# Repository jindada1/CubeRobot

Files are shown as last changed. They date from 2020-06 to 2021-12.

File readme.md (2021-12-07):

# 三阶魔方还原机器人

基于 python 和 Arduino，实现能够还原三阶魔方的机械结构

## 系统流程

1. 通过摄像头识别魔方颜色
2. 将识别结果转化成魔方求解算法的输入
3. 执行魔方求解算法，得出还原操作序列
3. 指令优化与碰撞规避处理
4. 通过wifi将序列发给硬件控制器
5. 硬件控制器按照序列，控制机械结构执行还原
6. over

## 依赖

python 版本: 3.x

+ pywifi
+ pillow
+ numpy
+ opencv-python 

```bash
$ pip install -r requirements.txt
$ python3 guiconfig.py
```

## 开发

### 软件部分

- [x] tkinter gui [组件](https://github.com/jindada1/CubeRobot/tree/master/components)的设计与开发

  - [x] Camera：基于cv2.VideoCapture 构造的摄像头管理类 
  
  - [x] HoverButton：基于 tk.Button 提供可带参数事件绑定接口，并做了些许美化
  
  - [x] ViewCanvas：**颜色数据采集与调试工具**中的面板，用于展示视频与图片
  
  - [x] CubeFloorPlan：用于绘制并管理魔方平面展开图，存储并管理整个魔方的色块分布，并生成魔方色块序列
  
  - [x] HSVAdjuster：**颜色数据采集与调试工具**中的面板，实时调整颜色识别中使用的 hsv 范围并保存
  
  - [x] SampleAdjuster：**颜色数据采集与调试工具**中的面板，实时调整用于颜色识别的采样范围并保存

  - [x] Console：控制台模块，用于**主控程序**运行时的状态输出

  - [x] Window：Tk 窗口的封装，提供了 update_func 接口
  
  - [x] CameraCanvas：摄像头视频展示面板，用于**主控程序**

- [x] [颜色数据采集与调试工具](https://github.com/jindada1/CubeRobot/blob/master/guiconfig.py)的开发

  - [x] [数据设置与加载模块](https://github.com/jindada1/CubeRobot/tree/master/setting)

  - [x] [计算机视觉模块](https://github.com/jindada1/CubeRobot/blob/master/vision.py)：魔方定位与颜色块的识别

    - [x] 全局二值化色块定位
  
    - [x] 形态学处理与魔方定位
  
    - [x] 手动定位，固定点采样
  
    - [x] 颜色识别

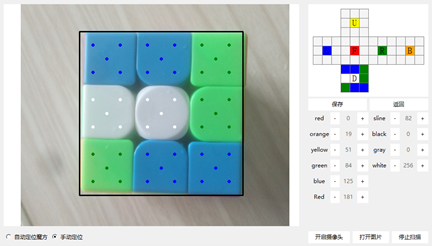
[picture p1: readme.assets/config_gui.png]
config_gui
  
  
- [x] [魔方模拟器](https://github.com/jindada1/CubeRobot/blob/master/sock/emulator.html)的开发

  - [x] 虚拟魔方的实现
- [x] 执行还原序列
  - [x] 获取魔方状态
- [x] twophase 求解接口的[后台服务器](https://github.com/jindada1/CubeRobot/blob/master/sock/http_server.py)
  
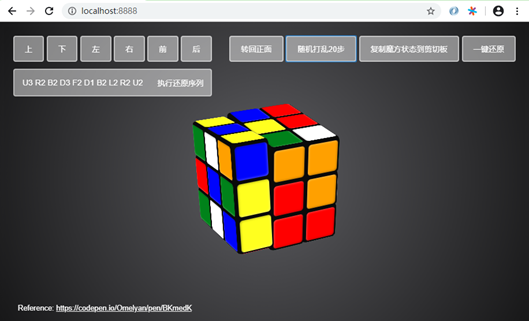
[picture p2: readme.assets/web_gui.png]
web_gui


- [x] 主控程序的开发

  - [x] [计算机视觉模块](https://github.com/jindada1/CubeRobot/blob/master/vision.py)：魔方定位与颜色块的识别
  - [x] [魔方求解模块](https://github.com/jindada1/CubeRobot/tree/master/twophase)：[twophase](https://github.com/hkociemba/RubiksCube-TwophaseSolver)算法
  - [x] 指令调整与优化
    
    - [x] 机器动作指令集的设计
    
    - [x] 标准还原序列到机器动作指令序列的转化
    
    - [x] 碰撞规避处理
  - [x] [wifi模块](https://github.com/jindada1/CubeRobot/blob/master/sock/esp_client.py)
  
    - [x] wifi检测与连接
    - [x] 自动获取 esp8266 模块在 ap 模式下的 ip 地址
    - [x] 发送数据和接收数据
  
  软件架构如下：
  
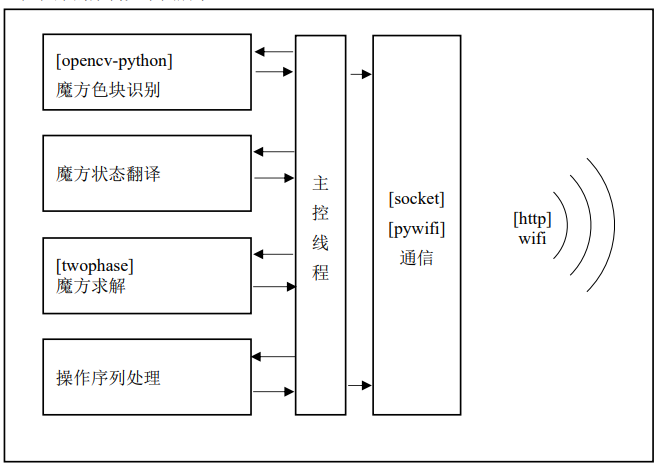
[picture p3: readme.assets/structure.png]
structure
  
  
  界面如下：
  
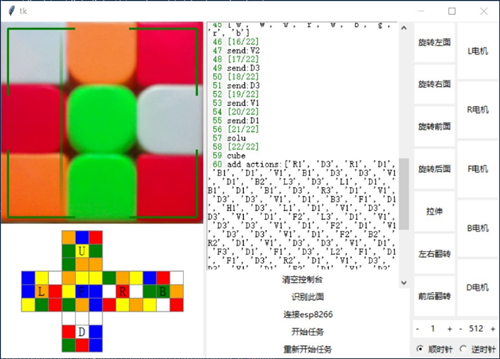
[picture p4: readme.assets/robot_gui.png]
robot_gui
  

### 硬件部分

- [x] esp8266

  - [x] ap 模式

  - [x] 提供路由处理来自客户端的请求，并返回处理结果

- [x] 操作序列的解析

- [x] 电机控制逻辑

  - [x] 单个电机动作控制

  - [x] 多个电机同步运行

  - [x] 单个电机角度微调

单个电机的基本连接如下：

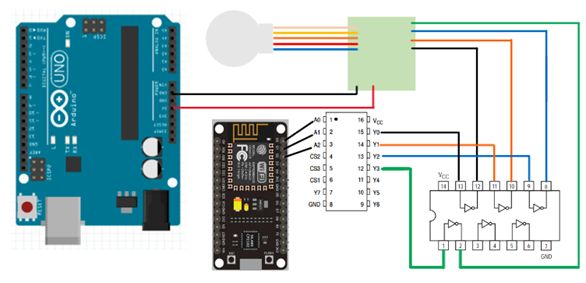
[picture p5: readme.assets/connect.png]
connect


## 机械结构建模

模型及装配体如下图所示，所有原文件在[sldprt](/models/sldprt)目录下

凹槽凸轮

导出的3D打印模型在[stl](/models/stl)目录下

### 动图演示

凹槽凸轮             |  魔方翻转       
:-------------------------:|:-------------------------:
  |  

|装配爆炸视图           |
|:-------------------------:|
|  |

### 实物照片

翻转魔方             |  魔鬼接线       
:-------------------------:|:-------------------------:
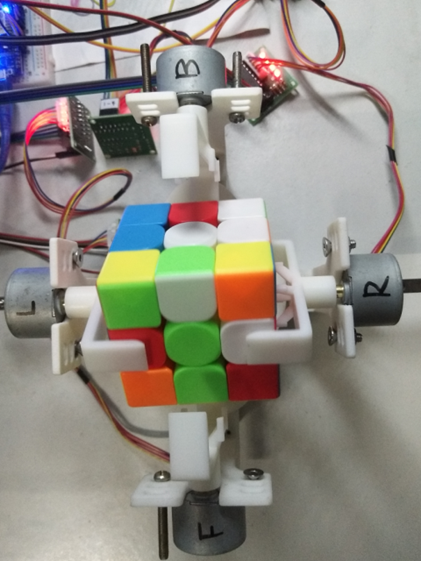
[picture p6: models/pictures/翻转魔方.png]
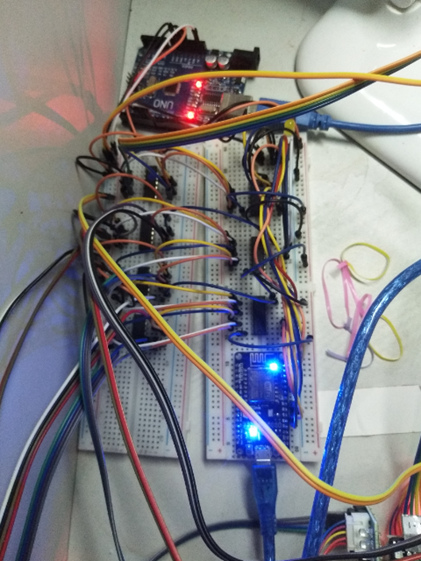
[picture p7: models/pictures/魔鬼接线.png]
  |  

识别魔方色块分布             |  旋转魔方面       
:-------------------------:|:-------------------------:
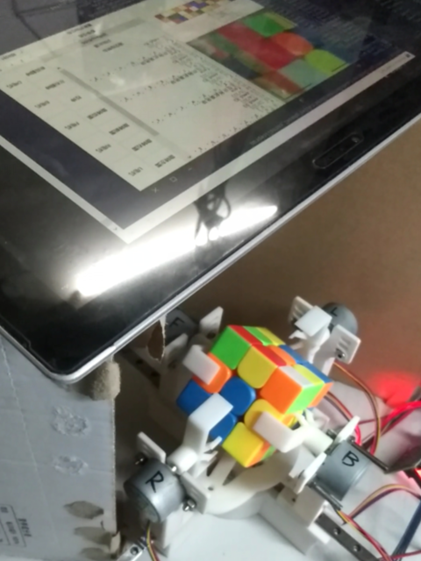
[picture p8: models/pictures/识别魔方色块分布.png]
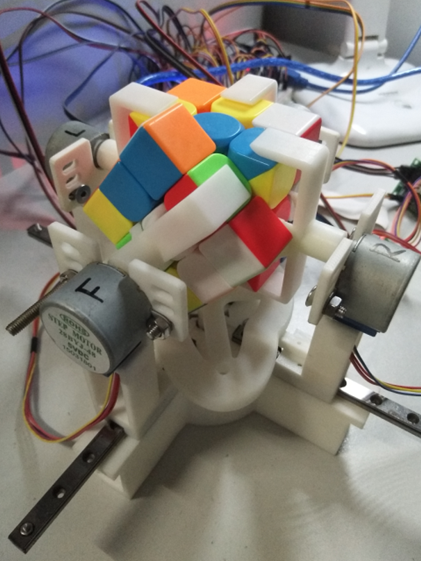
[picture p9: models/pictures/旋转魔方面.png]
  |

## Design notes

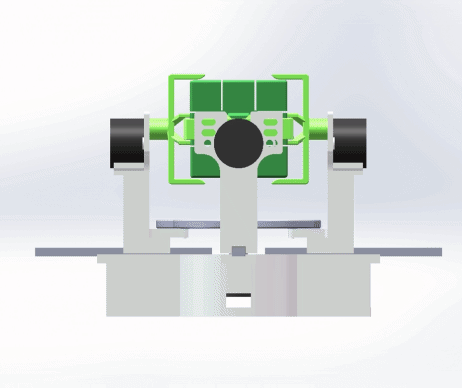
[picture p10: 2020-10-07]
models/screenshots/翻转.gif

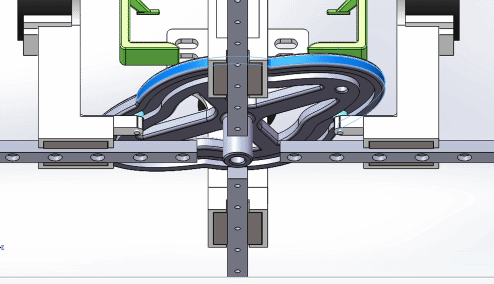
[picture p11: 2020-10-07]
models/screenshots/凹槽凸轮.gif

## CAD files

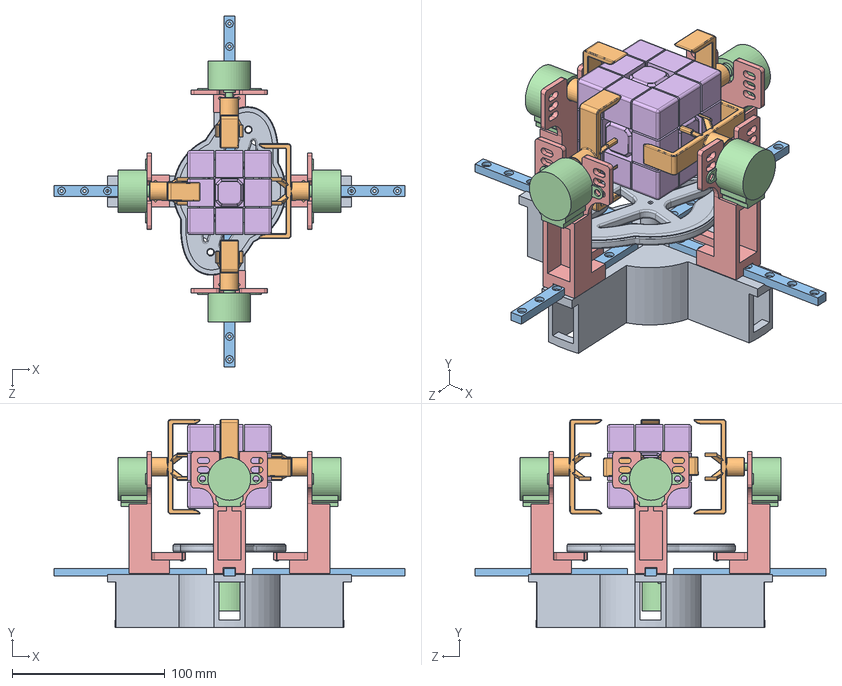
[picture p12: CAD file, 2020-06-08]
models/sldprt/机器人.SLDASM
230.0 x 136.6 x 230.0 mm
外壳
滑块 x 4
导轨 x 4
电机模型 x 5
机械臂拖 x 4
魔方55
轴承 x 5
螺栓m2 x 5
凹槽凸轮---
新抓手 x 4

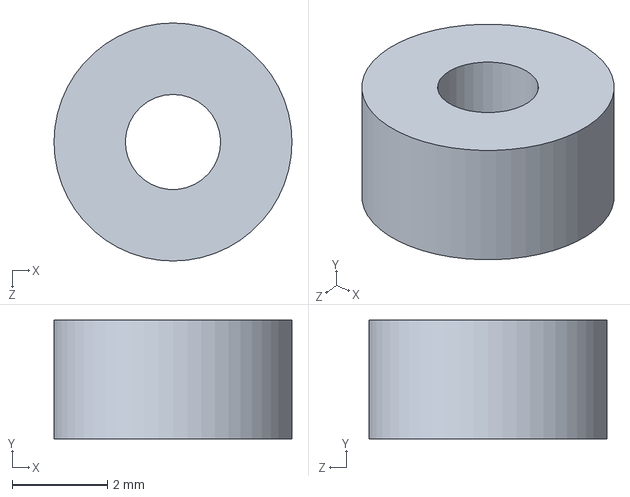
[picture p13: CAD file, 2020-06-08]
models/sldprt/轴承.sldprt
5.00 x 2.50 x 5.00 mm

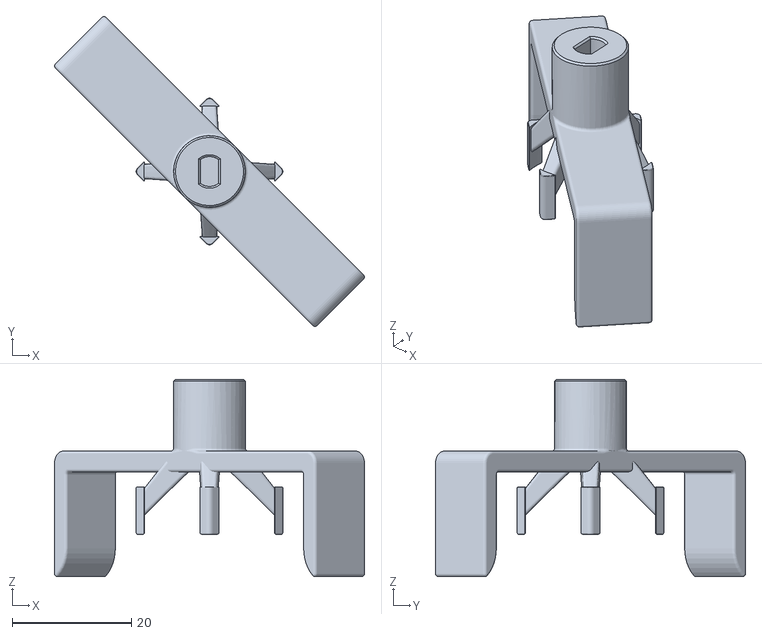
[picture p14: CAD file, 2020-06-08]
models/stl/新爪子x4-sla.STL
51.9 x 51.9 x 33.0

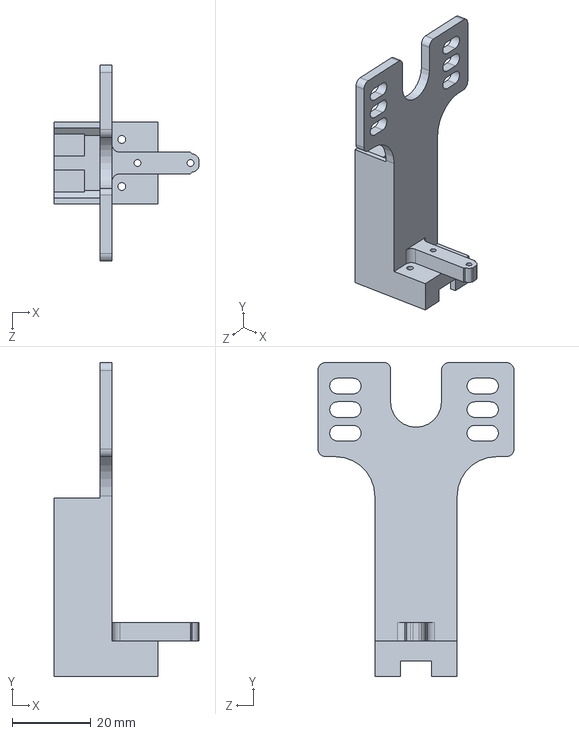
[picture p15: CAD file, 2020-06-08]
models/sldprt/机械臂.SLDPRT
36.9 x 80.0 x 50.0 mm

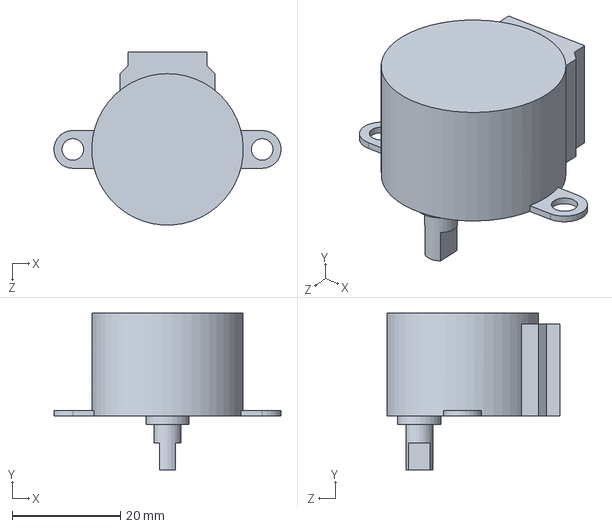
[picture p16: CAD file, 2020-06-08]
models/sldprt/电机模型.sldprt
41.9 x 29.0 x 32.0 mm

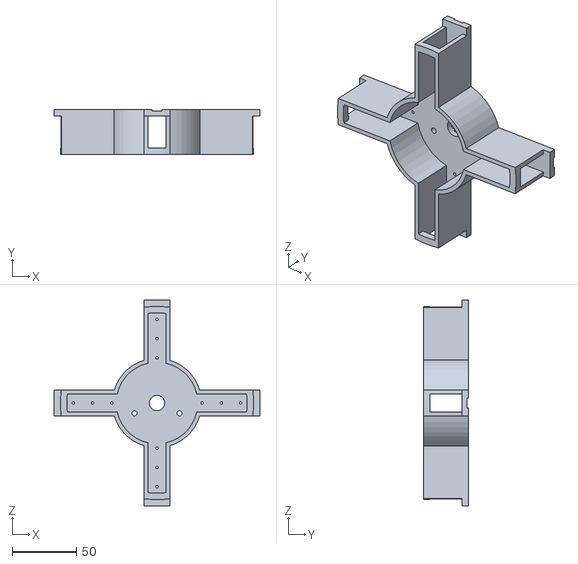
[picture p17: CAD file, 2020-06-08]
models/stl/外壳x1-pla.STL
160.0 x 35.0 x 160.0

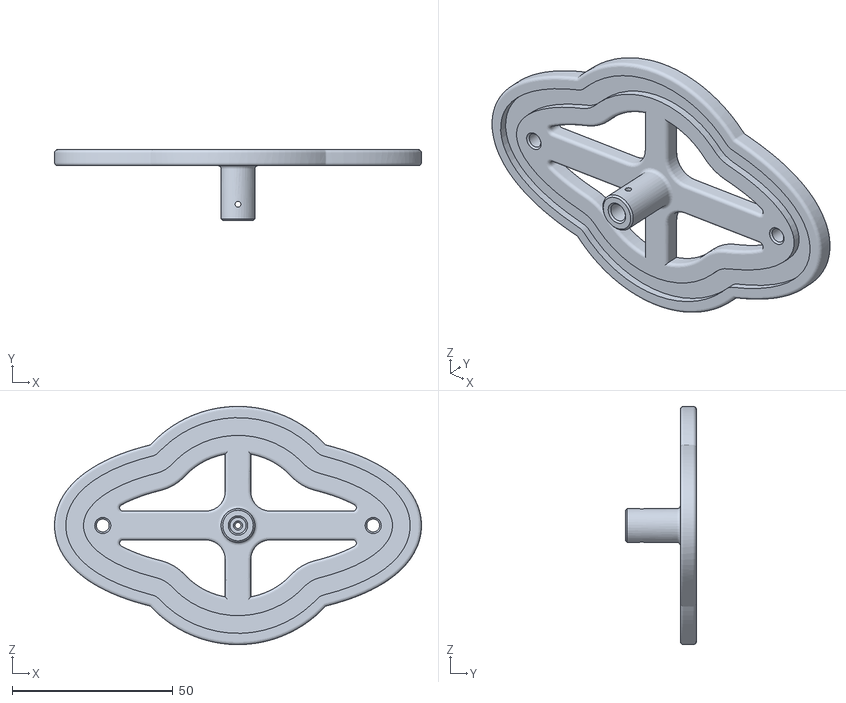
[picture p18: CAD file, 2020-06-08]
models/stl/凹槽凸轮x1-sla .STL
114.0 x 22.0 x 74.0

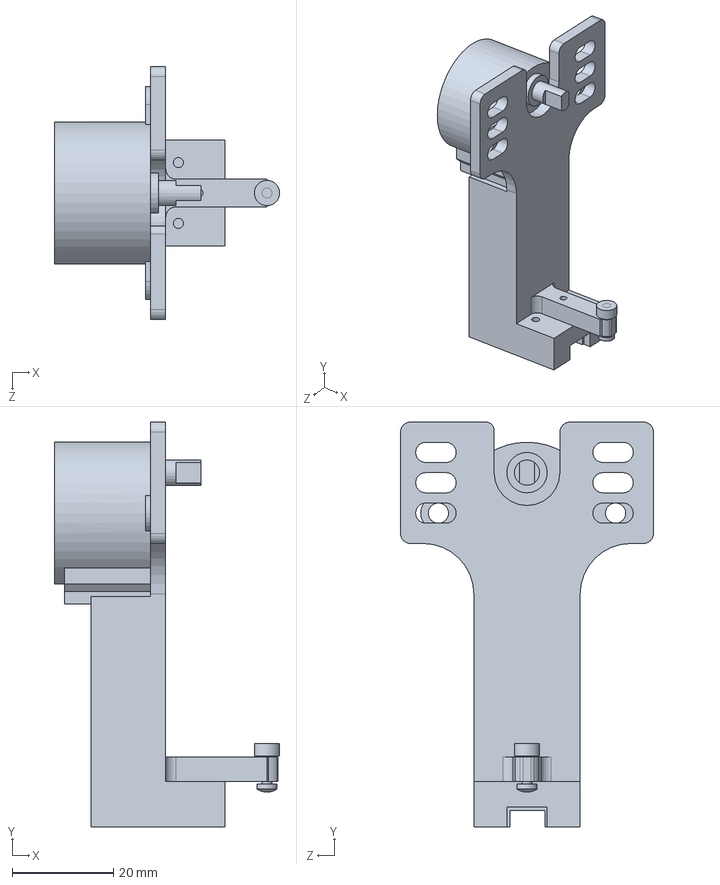
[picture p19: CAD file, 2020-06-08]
models/sldprt/B电机推块装配.SLDPRT
44.5 x 80.0 x 50.0 mm

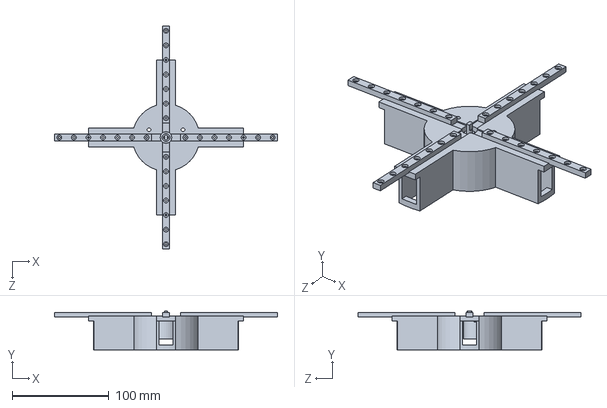
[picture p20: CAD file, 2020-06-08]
models/sldprt/A底座装配.SLDPRT
230.0 x 40.0 x 230.0 mm

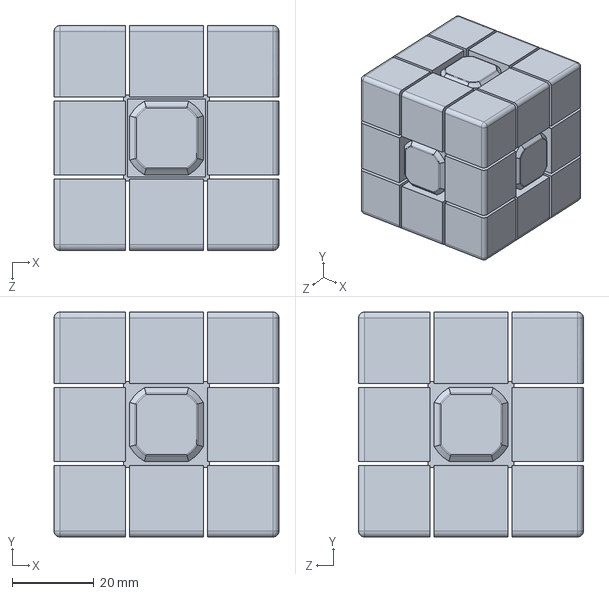
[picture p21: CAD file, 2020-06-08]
models/sldprt/魔方55.sldprt
55.0 x 55.0 x 55.0 mm

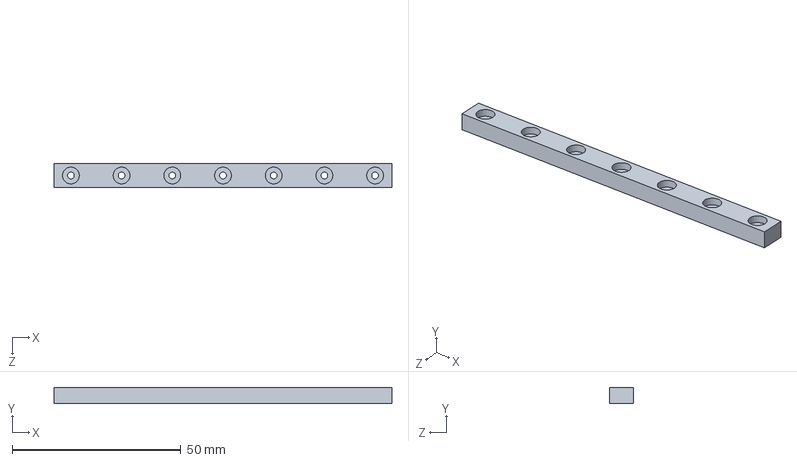
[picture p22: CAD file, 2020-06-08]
models/sldprt/滑轨.SLDPRT
100.0 x 4.80 x 7.00 mm

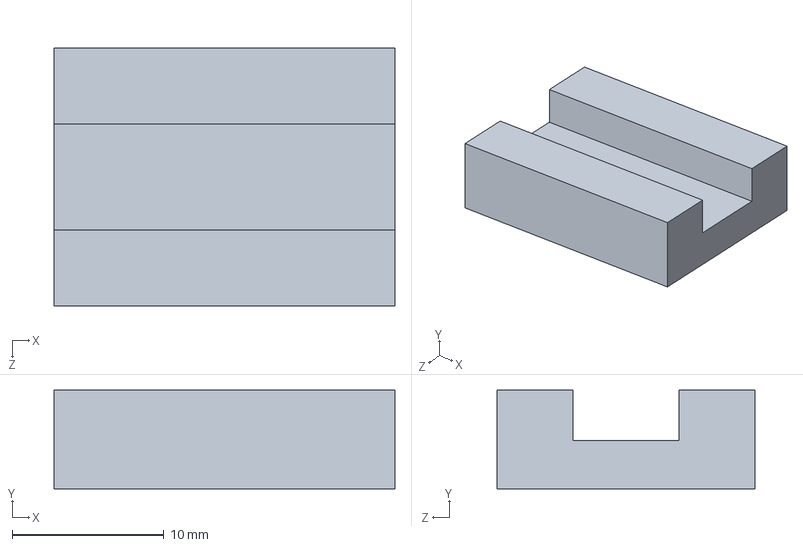
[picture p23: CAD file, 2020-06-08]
models/sldprt/滑块.sldprt
22.5 x 6.50 x 17.0 mm

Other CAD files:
models/stl/机械臂拖x4-pla.STL
models/sldprt/新抓手.SLDPRT
models/sldprt/凹槽凸轮.SLDPRT
models/sldprt/外壳底座.SLDPRT

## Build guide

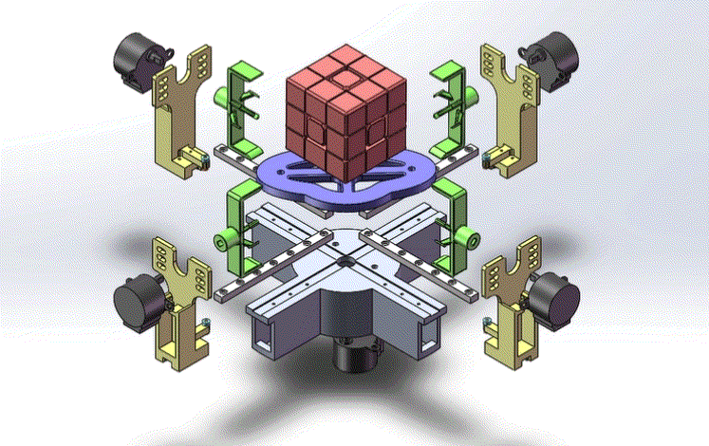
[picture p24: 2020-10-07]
models/screenshots/装配.gif

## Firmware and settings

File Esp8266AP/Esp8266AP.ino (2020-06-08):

/*
   reference:
   1.Getting query parameters
   ->:https://techtutorialsx.com/2016/10/22/esp8266-webserver-getting-query-parameters/
**/

/* Create a WiFi access point and provide a web server on it. */

#include <ESP8266WiFi.h>
#include <WiFiClient.h>
#include <ESP8266WebServer.h>

#ifndef APSSID
#define APSSID "Rubik-Cube"
#define APPSK "1213141516"
#endif

class myStepper
{
public:
  myStepper(int *p, char *cs[4], int r = 512)
  {
    pins = p;
    codes = cs;
    phase = 0;
    pinNum = 3;
    rot = r;
  };

  void step(int dir)
  {
    for (int i = 0; i < pinNum; i++)
    {
      digitalWrite(pins[i], codes[phase][i] == '1');
    }

    phase += dir;
    // dir == 1
    if (phase > 3)
      phase = 0;
    // dir == -1
    else if (phase < 0)
      phase = 3;
  };

  void rotate(int deg, int direct)
  {
    // phase = 0;
    deg = rot * deg;
    while (deg > 0)
    {
      step(direct);
      deg--;
      delay(3);
    }
  };

  void r_steps(int steps, int direct)
  {
    while (steps > 0)
    {
      step(direct);
      steps--;
      delay(3);
    }
  };

  int rots() { return rot; }

private:
  int pinNum;
  int *pins;
  char **codes;
  // 当前高电平所在的相位
  int phase;
  // 单位角度对应的 step 数，也就是90°对应的step数512
  int rot;
};

/* D0 16, D1 5, D2 4, D3 0, D4 2, D5 14, D6 12, D7 13, D8 15 */
int PINS[9] = {0, 2, 4, 5, 12, 13, 14, 15, 16};
char *P1[4] = {"000", "001", "010", "011"};
char *P2[4] = {"100", "101", "110", "111"};

int GROUP_1[3] = {12, 13, 15};
int GROUP_2[3] = {0, 2, 14};
int GROUP_3[3] = {16, 5, 4};

myStepper Left(GROUP_1, P1);
myStepper Right(GROUP_2, P1);
myStepper Front(GROUP_1, P2);
myStepper Back(GROUP_2, P2);
myStepper Down(GROUP_3, P1, 256);

/* Set these to your desired credentials. */
const char *ssid = APSSID;
const char *password = APPSK;

ESP8266WebServer server(80);

void initPins()
{
  for (int i = 0; i < 9; i++)
    pinMode(PINS[i], OUTPUT);
}

void config(char face, int steps, int clockwise)
{
  switch (face)
  {
  case 'L':
    Left.r_steps(steps, clockwise);
    break;

  case 'R':
    Right.r_steps(steps, clockwise);
    break;

  case 'F':
    Front.r_steps(steps, clockwise);
    break;

  case 'B':
    Back.r_steps(steps, clockwise);
    break;

  case 'D':
    Down.r_steps(steps, clockwise);
    break;

  default:
    break;
  }
}

void flip(myStepper L, myStepper R, int deg, int dir)
{
  int steps = L.rots() * deg;
  while (steps > 0)
  {
    L.step(dir);
    R.step(-dir);
    steps--;
    delay(3);
  }
}

void act(char face, int deg, int clockwise)
{
  switch (face)
  {
  case 'L':
    Left.rotate(deg, clockwise);
    break;

  case 'R':
    Right.rotate(deg, clockwise);
    break;

  case 'F':
    Front.rotate(deg, clockwise);
    break;

  case 'B':
    Back.rotate(deg, clockwise);
    break;

  case 'D':
    Down.rotate(deg, clockwise);
    break;

  case 'H':
    flip(Front, Back, deg, clockwise);
    break;

  case 'V':
    flip(Left, Right, deg, clockwise);
    break;

  default:
    break;
  }
}

void onIndex()
{
  Serial.println("/");
  server.send(200, "text/html", "<h1>You are connected</h1>");
}

void onConfig()
{
  Serial.println("/config");
  if (server.hasArg("steps"))
  {
    char face = (server.arg("face").c_str())[0];
    int steps = atoi(server.arg("steps").c_str());
    int clockwise = atoi(server.arg("clockwise").c_str());
    config(face, steps, clockwise);
  }
  server.send(200, "text/plain", "/config"); //Response to the HTTP request
}

void onAction()
{
  Serial.println("/action");
  if (server.hasArg("deg"))
  {
    char face = (server.arg("face").c_str())[0];
    int deg = atoi(server.arg("deg").c_str());
    int clockwise = atoi(server.arg("clockwise").c_str());
    act(face, deg, clockwise);
  }
  server.send(200, "text/plain", "/action"); //Response to the HTTP request
}

void funny()
{
  int steps = 1024;
  while (steps > 0)
  {
    Front.step(1);
    Back.step(-1);
    if(steps%2) Down.step(1);
    steps--;
    delay(3);
  }
  steps = 1024;
  while (steps > 0)
  {
    Left.step(1);
    Right.step(-1);
    if(steps%2) Down.step(1);
    steps--;
    delay(3);
  }
  server.send(200, "text/plain", "have a nice day!");
}

void setup()
{
  delay(1000);
  Serial.begin(115200);
  initPins();
  openWifi();
  setupRouters();
}

void openWifi()
{
  Serial.println("\n Configuring access point...");
  WiFi.softAP(ssid, password);

  IPAddress myIP = WiFi.softAPIP();
  Serial.print("AP IP address: ");
  Serial.println(myIP);
}

void setupRouters()
{
  server.on("/", onIndex);
  server.on("/config", onConfig);
  server.on("/action", onAction);
  server.on("/funny", funny);
  server.begin();
  Serial.println("HTTP server started");
}

void loop()
{
  server.handleClient();
}

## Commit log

2020-03-20 hsv color filter
2020-03-21 add manual detector and sample data
2020-03-22 sample adjuster
2020-03-25 [refract] extract video from cameracanvas
2020-04-03 [add] controller thread
2020-04-08 [add] socket client class
2020-04-11 [add] socket_http_server
2020-04-13 [add] control flow & pc ↔ esp
2020-06-08 [add] models
    [A底座装配.SLDPRT, B电机推块装配.SLDPRT, 凹槽凸轮.SLDPRT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]
2020-10-07 更新图片
2021-03-16 更新 readme
